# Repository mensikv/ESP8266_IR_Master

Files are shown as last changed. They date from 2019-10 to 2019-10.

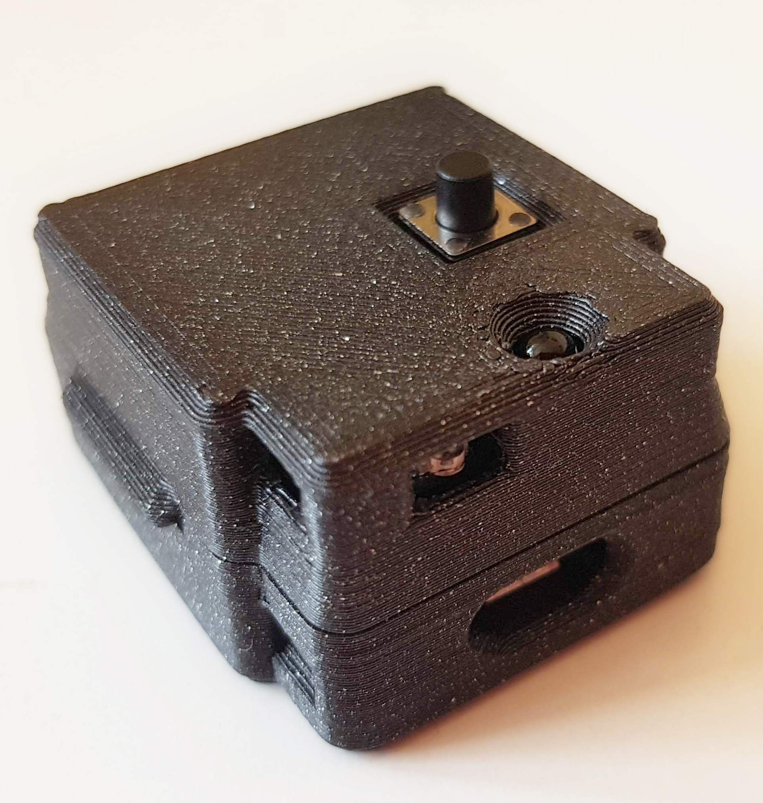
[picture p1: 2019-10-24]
photos/ESP8266_IR_Master_1.jpg

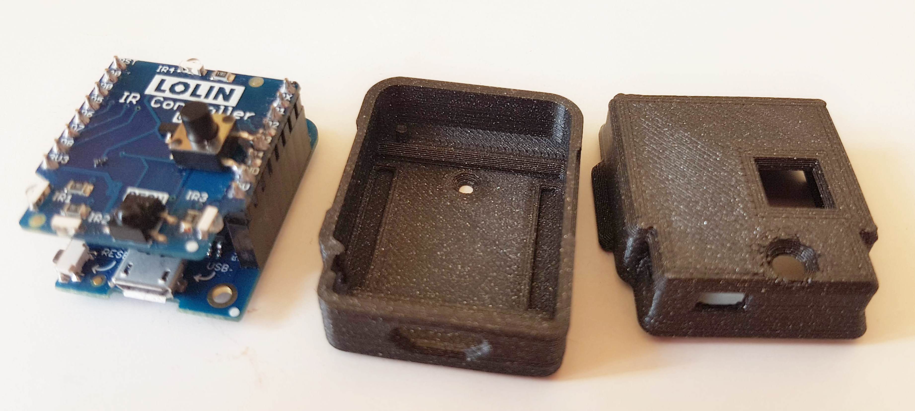
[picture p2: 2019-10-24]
photos/ESP8266_IR_Master_4.jpg

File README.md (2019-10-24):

# ESP8266 IR Master
The project is for ESP8266 boards and utilizes IR LEDs and IR receiver. Thanks to the IR receiver, you can scan various IR codes (from tv remotes, air-conditionings, lights...), save them to EEPROM on the ESP8266 and later send them through the IR LEDs.
Webserver runs on ESP8266 that provides interface for scanning and sending of IR codes. REST and MQTT API can also be enabled.
Project can be used in home automation systems for devices, that are controlled with IR remotes.
**WIFI networks is required**.

This project was created for workshop on [Mini Maker Fair Brno 2019](https://brno.makerfaire.com/).

## Prerequisites
### Hardware
It is possible to use any ESP8266 board and some IR LEDs and IR receiver, but I would recommend following combination:
* [Wemos (Lolin) D1 Mini](https://lolin.aliexpress.com/store/group/D1-D1-mini-Boards/1331105_505460007.html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) (non-affiliated link)
* [Wemos (Lolin) IR shield](https://www.aliexpress.com/item/32891173618.html?spm=2114.12010612.8148356.1.32522730sTPRit) (non-affiliated link)

### Software
Project was tested with following versions:
* Arduino IDE 1.8.10
* ESP8266 core 2.5.2
* [ESP8266 Sketch Data Upload](https://github.com/esp8266/arduino-esp8266fs-plugin)

Libraries:
* [ArduinoJSON 6.12.0](https://github.com/bblanchon/ArduinoJson)
* [ESP_EEPROM 2.0.0](https://github.com/jwrw/ESP_EEPROM)
* [IRRemoteESP8266 2.6.6](https://github.com/crankyoldgit/IRremoteESP8266)
* [WifiManages 0.15.0-beta](https://github.com/tzapu/WiFiManager)
* [arduinoWebSockets 2.1.1](https://github.com/Links2004/arduinoWebSockets)
* [PubSubClient 2.7](https://github.com/knolleary/pubsubclient)
* [PinButton](https://github.com/poelstra/arduino-multi-button)

## Sending IR codes with a button
You can use a button to send selected IR codes, single click and double click is supported.
If you use Wemos D1 Mini with [IR shield](https://wiki.wemos.cc/products:d1_mini_shields:ir_controller_shield), use these steps:
1. Solder a button on the IR shield between pins D3 and GND.
1. Since D3 is by default used for IR LEDs, you must cut a trace on the back of the IR shield and join two solder pads - I have used pin D2 for IR LEDs.

## Setup
1. Download content of this repository to your Arduino folder (probably `~\Documents\Arduino\ESP8266_IR_Master`, folder should contain one `*.ino` file and `data` folder) and open `ESP8266_IR_Master.ino`.
1. Set pin for sending IR signals `const uint16_t kIrLedPin = D2;`
1. Set pin for receiving IR signals `const uint16_t kRecvPin = D4;`
1. You can set a hostname by changing `#define ESP_HOSTNAME "IRMASTER001"`
1. If you want to use button, set the pin, where button is connected: `#define BUTTON_PIN D3`
1. If you want to enable REST API (sending IR codes with GET requests), uncomment `//#define USE_REST_API`
1. If you want to enable MQTT API (sending IR codes with MQTT messages), uncomment `//#define USE_MQTT`
   1. In section `#ifdef USE_MQTT` set connection to your MQTT broker and topics, you want to use.
   1. You should increase `MQTT_MAX_PACKET_SIZE` in PubSubClient.h. For 5 IR codes is 512 sufficient - `#define MQTT_MAX_PACKET_SIZE 512`
1. If you want to assign static IP address to the board in your WIFI network, uncomment and set following line `//wifiManager.setSTAStaticIPConfig(IPAddress(192,168,0,99), IPAddress(192,168,0,1), IPAddress(255,255,255,0));`
1. Choose the right board and select Flash size with at least 128kB SPIFFS, on Wemos D1 Mini I have used 4M (1M SPIFFS)
1. Upload the code.
1. Run ESP8266 Sketch Data Upload to upload content of `/data` folder to SPIFFS on ESP8266. Great article is [Chapter 11 - SPIFFS](https://tttapa.github.io/ESP8266/Chap11%20-%20SPIFFS.html). ESP8266 Sketch Data Upload plug-in to load data on SPIFFS can be downloaded from [here](https://github.com/esp8266/arduino-esp8266fs-plugin). `/data` folder contains html code, CSS styles and JavaScript code for the webserver.
   1. Before stating upload to SPIFFS make sure, that Serial monitor window is not opened, otherwise the upload will fail.
1. Now the ESP8266 will start in AP mode (onboard LED blinks) and creates WIFI network with the name you set as hostname. Connect to this network and you should be redirected to URL 192.168.0.1 (if not, enter this address in your browser). On this page set up WIFI connection to your network. ESP8266 will try to connect to it, if it succeeds the onboard LED stops blinking.
1. Either check your router or Serial monitor to find out, what IP address the ESP8266 got. Enter this address in your browser.
1. You enter a web interface with 3 tabs, 1st tab is used to send IR codes (it is empty, until you scan and save some IR codes). 2nd tab is used to scan new IR codes (click Scan button and then you have 5seconds to fire IR signal on the IR receiver. If successful, you can name it and save), delete some IR codes and also assign some codes to click or double click of the button. 3rd tab is short help.

## REST API
If you enable REST API, then the ESP8266 will provide two new URLs:
* http://IPADDRESS/api?all
  * returns JSON with saved IR codes and their IDs
* http://IPADDRESS/api?fire=IR_ID
  * sends IR signal with id IR_ID and returns JSON with success or error

## MQTT API
If you enable MQTT API, then the ESP8266 will wait for commands in topic:
* MQTT_TOPIC/cmd with payloads
  * "all" - returns JSON with saved IR codes in topic MQTT_TOPIC/all
  * "fire IR_ID" - sends IR signal with id IR_ID and returns JSON with success or error in topic MQTT_TOPIC/fire

## STL for case
In folder `case` you will find `*.stl` files for your 3D printer, so you can print nice case for Wemos D1 Mini with IR shield.
More information about the case and photos can be found on [Thingiverse](https://www.thingiverse.com/thing:3930823).

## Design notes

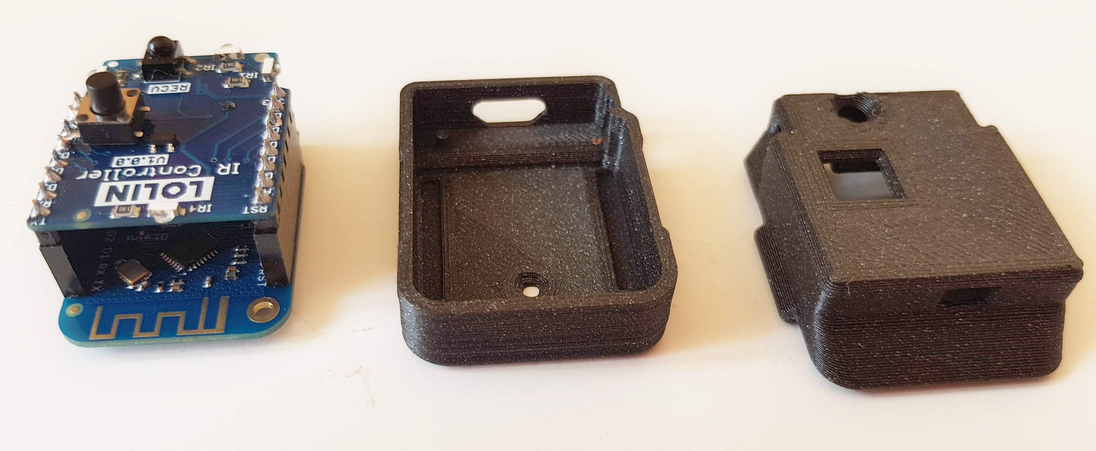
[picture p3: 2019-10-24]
photos/ESP8266_IR_Master_5.jpg

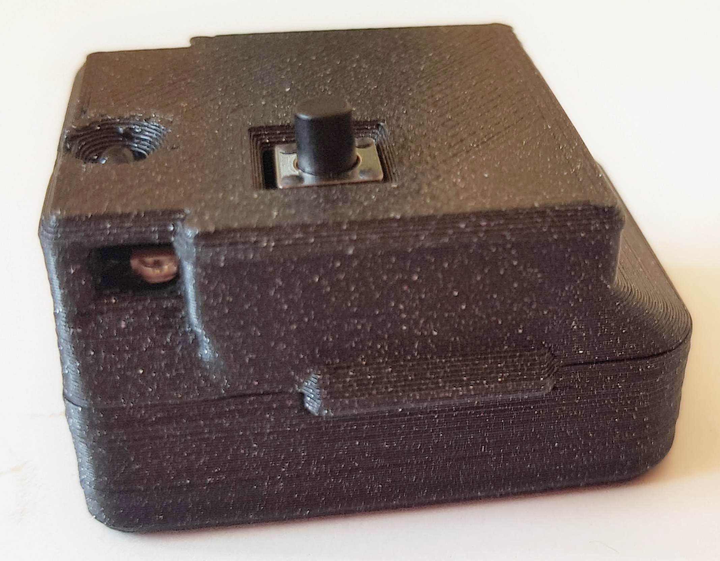
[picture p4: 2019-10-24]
photos/ESP8266_IR_Master_2.jpg

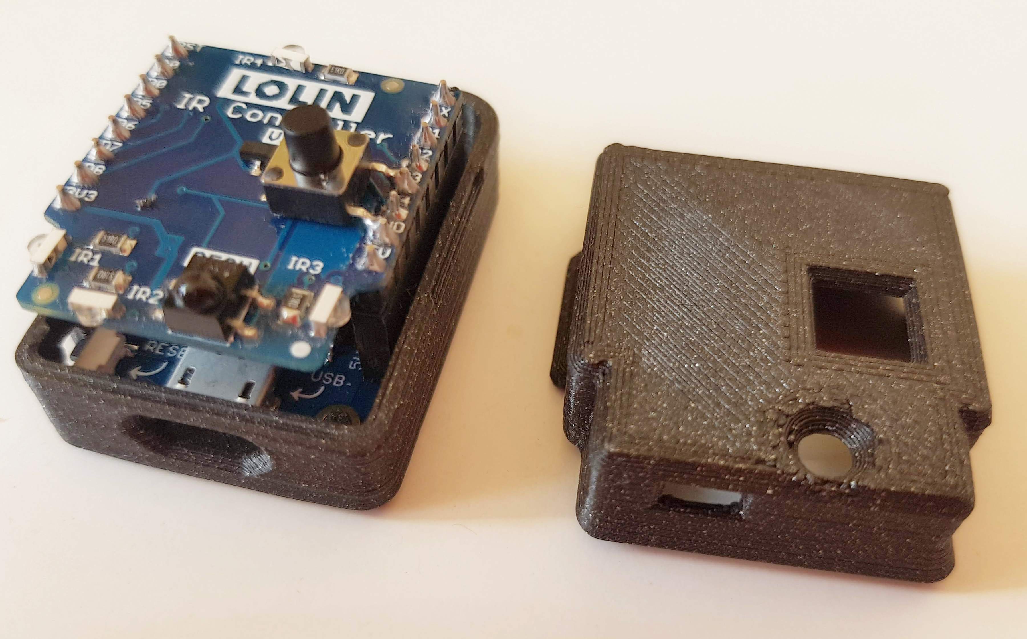
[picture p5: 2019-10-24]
photos/ESP8266_IR_Master_3.jpg

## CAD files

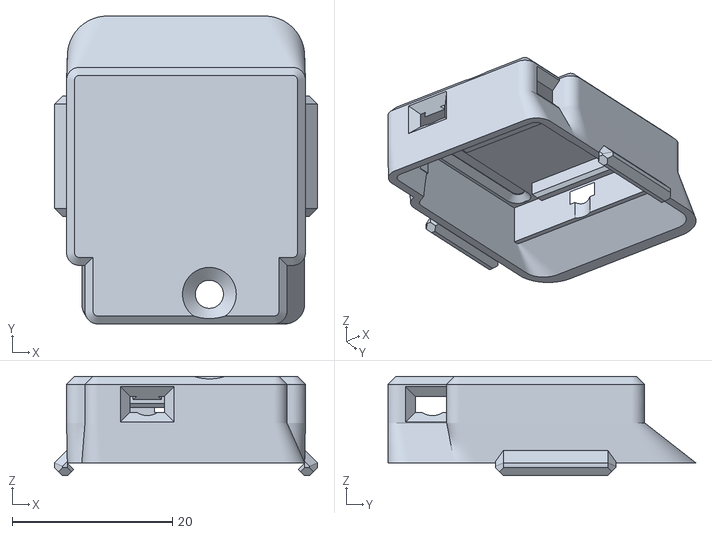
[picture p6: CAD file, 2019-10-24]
case/ESP8266_IR_Master-case-top.stl
32.8 x 38.4 x 12.4

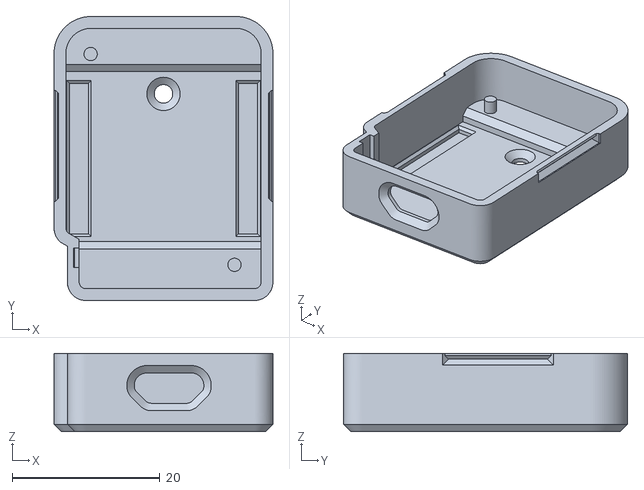
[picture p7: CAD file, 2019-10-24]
case/ESP8266_IR_Master-case-bottom.stl
29.6 x 38.4 x 10.6

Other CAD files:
case/ESP8266_IR_Master-case-top-button.stl

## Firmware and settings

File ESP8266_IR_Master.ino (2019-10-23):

/*
  ####
  ## ESP8266 IR Master
  ####
  Board: Lolin(Wemos) D1 R2 & mini
  Flash size: 4M (1M SPIFFS)
  When you want to erase EEPROM: Erase Flash: All Flash Contents

  upload code a then upload files

  use ESP8266 Sketch Data Upload to upload files to ESP8266 SPIFFS: // https://github.com/esp8266/arduino-esp8266fs-plugin
  data\index.html.gz
  data\bootstrap.min.js.gz
  data\jquery-3.4.1.min.js.gz
  data\bootstrap.min.css.gz
  data\favicon.ico

  Tested with versions:
  Arduino IDE 1.8.10

  ESP8266 core 2.5.2

  Libraries:
  ArduinoJSON 6.12.0
  ESP_EEPROM 2.0.0
  IRRemoteESP8266 2.6.6
  WifiManages 0.15.0-beta
  arduinoWebSockets 2.1.1
  PubSubClient 2.7
    you should increase MQTT_MAX_PACKET_SIZE in PubSubClient.h for 5 irCodes is 512 sufficient
      #define MQTT_MAX_PACKET_SIZE 512
*/

#include <Arduino.h>
#include <FS.h>
#include <Ticker.h>
#include <ESP8266WiFi.h>          //ESP8266 Core WiFi Library
#include <DNSServer.h>            //Local DNS Server used for redirecting all requests to the configuration portal - needed for WifiManager
#include <ESP8266WebServer.h>     //Local WebServer used to serve the configuration portal

#include <WiFiManager.h>          // https://github.com/tzapu/WiFiManager WiFi Configuration Magic
#include <ESP_EEPROM.h>           // https://github.com/jwrw/ESP_EEPROM
#include <PinButton.h>            // https://github.com/poelstra/arduino-multi-button
#include <ArduinoJson.h>          // https://github.com/bblanchon/ArduinoJson
#include <WebSocketsServer.h>     // https://github.com/Links2004/arduinoWebSockets
#include <IRremoteESP8266.h>      // https://github.com/crankyoldgit/IRremoteESP8266
#include <IRrecv.h>
#include <IRsend.h>
#include <IRutils.h>

/*
  ## WIFI Manager function
  When your ESP starts up, it sets it up in Station mode and tries to connect to a previously saved Access Point
  if this is unsuccessful (or no previous network saved) it moves the ESP into Access Point mode and spins up a DNS and WebServer (ip 192.168.0.1)
  using any wifi enabled device with a browser (computer, phone, tablet) connect to the newly created Access Point
  because of the Captive Portal and the DNS server you will either get a 'Join to network' type of popup or get any domain you try to access redirected to the configuration portal
  choose one of the access points scanned, enter password, click save
  ESP will try to connect. If successful, it relinquishes control back to your app. If not, reconnect to AP and reconfigure.
*/

#define ESP_HOSTNAME "IRMASTER001"

#define IR_CODE_COUNT 5                       // Number of IR codes that could be learned
#define IR_CODE_NAME_MAX_LENGTH 20            // Maximum length of IR code name (excluding ending 0)
#define IR_DEFAULT_REPEAT_COUNT 2             // how many times is an IR code fired
#define IR_DEFAULT_REPEAT_INTERVAL_MS 5       // how many milliseconds between IR code firing
#define MAX_REC_IR_WAITING_TIME_MS 5000       // How long to wait for IR code when learning new one

// APIs - if one is not needed, it should be commented
//#define USE_REST_API                          // /api?all - JSON with all ir codes; /api?fire=irCodeIndex - sends ir Code with irCodeIndex index
//#define USE_MQTT                              // all/fire

#define BUTTON_PIN D3                         // Pin where the button is connected
#define KBAUDRATE 115200                      // The Serial connection baud rate.

#define BUTTON_NO_CLICK 0
#define BUTTON_SINGLE_CLICK 1
#define BUTTON_DOUBLE_CLICK 2

#ifdef USE_MQTT
#include <PubSubClient.h>                     // https://github.com/knolleary/pubsubclient
#define MQTT_SERVER "192.168.1.201"
#define MQTT_USERNAME "irmaster"
#define MQTT_PASSWORD "password"
#define MQTT_TOPIC           ESP_HOSTNAME
#define MQTT_CMD_TOPIC       MQTT_TOPIC "/cmd"                  // payload "all", "fire x", where x is irCodeIndex
#define MQTT_ALL_TOPIC       MQTT_TOPIC "/all"                  // response JSON with all ir codes
#define MQTT_FIRE_TOPIC      MQTT_TOPIC "/fire"                 // response JSON with information about success or error
#define MQTT_LAST_WILL_TOPIC MQTT_TOPIC "/live"
#define MQTT_LAST_WILL "OFF"
#endif

// ==================== IRremoteESP8266 TUNEABLE PARAMETERS ====================
// The GPIO an IR detector/demodulator is connected to.
const uint16_t kRecvPin = D4;

// GPIO to use to control the IR LED circuit.
const uint16_t kIrLedPin = D2;

// As this program is a special purpose capture/resender, let's use a larger than expected buffer so we can handle very large IR messages.
const uint16_t kCaptureBufferSize = 1024;  // 1024 == ~511 bits

// kTimeout is the Nr. of milli-Seconds of no-more-data before we consider a message ended.
const uint8_t kTimeout = 50;  // Milli-Seconds

// kFrequency is the modulation frequency all UNKNOWN messages will be sent at.
const uint16_t kFrequency = 38000;  // in Hz. e.g. 38kHz.


// ==================== Types definition ====================
// structure to hold information about an IR code
typedef struct {
  char irCodeName[IR_CODE_NAME_MAX_LENGTH + 1];
  decode_type_t protocol;                   // NEC, SONY, RC5, UNKNOWN
  uint16_t irCodeLength;                    // number of bytes in irCodeState or number of bits in irCodeValue or number of raw data in irCodeRaw
  union {
    uint64_t irCodeValue;                   // Decoded value - a simple message protocol. ie. <= 64 bits
    uint8_t  irCodeState[kStateSizeMax];    // Multi-byte results for AC protocol with states
    uint16_t irCodeRaw[kRawBuf];
  };
} irCodeType;

// Settings
typedef struct {
  uint8_t irCodeCount;                  // 1 byte, Number of learned IR codes
  uint8_t singleClickIRCodeId;          // 1 byte, Index for IR code associated with button single click
  uint8_t doubleClickIRCodeId;          // 1 byte, Index for IR code associated with button double click
} irMasterSettingType;

typedef struct {                        // structure, that is written into the EEPROM memory
  uint32_t crc32;                       // 4 bytes
  irMasterSettingType irMasterSetting;
  irCodeType irCodes[IR_CODE_COUNT];
} irMasterEEPROMType;

// ==================== Global variables ====================
irMasterEEPROMType   irMasterEEPROM;          // contains all IR codes, CRC32 and other informations
irCodeType           *irCodes;                // IR codes the application operates with
irMasterSettingType  *irMasterSetting;        // Will containt info about button, number of learned IR codes and CRC32 of EEPROM
irCodeType irCode;                            // Will contain new IR code when learning

// Strings for storing JSON and IR codes
String strVar;   // reserve for 512 characters
String output;   // reserve for 768 characters

// The IR transmitter.
IRsend irsend(kIrLedPin);

// Web serever will run on port 80
ESP8266WebServer server(80);

// Websocket server will run on port 81
WebSocketsServer websocket_server = WebSocketsServer(81);

// Ticker is used to periodically call an function - we use it to blink the LED during WIFI setup
Ticker ticker;

// Create a new button object, listening on pin BUTTON_PIN = D3.
PinButton myButton(BUTTON_PIN);

#ifdef USE_MQTT
WiFiClient espWifiClient;
PubSubClient mqtt_client(espWifiClient);
#endif


// ==================== WIFI AP configuration ====================
// Function will turn on/off LED on Wemos board
void tick() {
  digitalWrite(LED_BUILTIN, !digitalRead(LED_BUILTIN));
}

// When Wifi Manager could not connecct to WIFI, it will start up its own AP with configuration portal. During configuration we will blink the LED
void startWMConfig(WiFiManager *wmp) {
  // every 200 ms call function tick
  ticker.attach(0.2, tick);
}

// Once WIFI configuration end, we stop blinking
void endWMConfig() {
  ticker.detach();
  digitalWrite(LED_BUILTIN, HIGH);
}


// ==================== ArduinoJSON examples ====================
/*
  //Adding array of objects - {"elem":[{"elem1":1},{"elem2":2}]}
  JsonArray elem = responseJSON.createNestedArray("elem");
  JsonObject elem1 = elem.createNestedObject();
  elem1["elem1"] = 1;
  JsonObject elem2 = elem.createNestedObject();
  elem2["elem2"] = 2;

  // Adding array {"elem":[1, 2]}
  JsonArray elem = responseJSON.createNestedArray("elem");
  elem.add(1);
  elem.add(2);

  // Adding Object {"elem":{"elem1":1,"elem2":2}}
  JsonObject elem = responseJSON.createNestedObject("elem");
  elem["elem1"] = 1;
  elem["elem2"] = 2;
*/

// ==================== JSON responses ====================
void allResponse (bool longFormat = false) {
  // create object for creating JSON
  //biggest JSON object:{"rsT":"all", "rsS":"OK", "rsE":"","rsV":[{"id":0,"name":"TV on", "ir":"123456", "btn":0},{"id":1,"name":"TV off", "ir":"987654", "btn":1},{"id":1,"name":"TV off", "ir":"987654", "btn":2},{"id":1,"name":"TV off", "ir":"987654", "btn":0},{"id":1,"name":"TV off", "ir":"987654", "btn":0}]}
  const int capacityResponseJSON = JSON_ARRAY_SIZE(5) + 6 * JSON_OBJECT_SIZE(4) + 256;
  StaticJsonDocument<capacityResponseJSON> responseJSON;
  //StaticJsonDocument<1024> responseJSON;
  responseJSON["rsT"] = "all";
  responseJSON["rsS"] = "OK";
  responseJSON["rsE"] = "";
  output = "";
  yield();
  //{rsT:"all", rsS:"OK", rsE:"",rsV:[{id:0,name:"TV on", ir:"123456", "btn":0},{id:1,name:"TV off", ir:"987654", "btn":1}]};
  JsonArray rsV = responseJSON.createNestedArray("rsV");
  for (uint8_t i = 0; i < IR_CODE_COUNT; i++) {
    if (irCodes[i].irCodeLength > 0) {
      JsonObject irCodeElem = rsV.createNestedObject();
      irCodeElem["id"] = i;
      irCodeElem["name"] = irCodes[i].irCodeName;
      if (longFormat) {
        irCodeElem["ir"] = getIRCode(&irCodes[i], false);
        if (i == irMasterSetting->singleClickIRCodeId) irCodeElem["btn"] = BUTTON_SINGLE_CLICK;
        else if (i == irMasterSetting->doubleClickIRCodeId) irCodeElem["btn"] = BUTTON_DOUBLE_CLICK;
        else irCodeElem["btn"] = BUTTON_NO_CLICK;
      }
    }
  }
  serializeJson(responseJSON, output);
  yield();
}

void scanResponse (uint8_t scanResult) {
  // create object for creating JSON
  const int capacityResponseJSON = JSON_OBJECT_SIZE(4) + 100;
  StaticJsonDocument<capacityResponseJSON> responseJSON;
  responseJSON["rsT"] = "scan";
  responseJSON["rsS"] = "OK";
  responseJSON["rsE"] = "";
  output = "";
  yield();
  //{"rsT":"scan", "rsS":"OK", "rsE":"","rsV":"123456"}
  if (scanResult == 1) {
    responseJSON["rsV"] = getIRCode(&irCode, false);
  } else {
    responseJSON["rsS"] = "ERROR";
    responseJSON["rsE"] = (scanResult == 0) ? "IR code scan timeout" : "IR code overflow";
  }
  serializeJson(responseJSON, output);
  yield();
}

void fireResponse (uint8_t fireResult, const uint8_t irCodeIndex) {
  // create object for creating JSON
  const int capacityResponseJSON = JSON_OBJECT_SIZE(4) + 60;
  StaticJsonDocument<capacityResponseJSON> responseJSON;
  responseJSON["rsT"] = "fire";
  responseJSON["rsS"] = "OK";
  responseJSON["rsE"] = "";
  responseJSON["rsV"] = irCodeIndex;
  output = "";
  yield();
  //{"rsT":"fire", "rsS":"OK", "rsE":"","rsV":9}
  if (fireResult != 1) {
    responseJSON["rsS"] = "ERROR";
    responseJSON["rsE"] = (fireResult == 0) ? "Error during sending of IR code" : "Non-existing index";
  }
  serializeJson(responseJSON, output);
  yield();
}

void deleteResponse (uint8_t deleteResult, const uint8_t irCodeIndex) {
  // create object for creating JSON
  const int capacityResponseJSON = JSON_OBJECT_SIZE(4) + 60;
  StaticJsonDocument<capacityResponseJSON> responseJSON;
  responseJSON["rsT"] = "delete";
  responseJSON["rsS"] = "OK";
  responseJSON["rsE"] = "";
  responseJSON["rsV"] = irCodeIndex;
  output = "";
  yield();
  //{"rsT":"delete", "rsS":"OK", "rsE":"","rsV":9}
  if (deleteResult != 1) {
    responseJSON["rsS"] = "ERROR";
    responseJSON["rsE"] = (deleteResult == 0) ? "Error during deleting operation" : "Non-existing index";
  }
  serializeJson(responseJSON, output);
  yield();
}

void learnResponse (uint8_t learnResult, const uint8_t irCodeIndex) {
  // create object for creating JSON
  const int capacityResponseJSON = 2 * JSON_OBJECT_SIZE(4) + 60;
  StaticJsonDocument<capacityResponseJSON> responseJSON;
  responseJSON["rsT"] = "learn";
  responseJSON["rsS"] = "OK";
  responseJSON["rsE"] = "";
  output = "";
  yield();
  //{"rsT":"learn", "rsS":"OK", "rsE":"","rsV":{"id":0,"name":"TV on", "ir":"123456", "btn":0}}
  if (learnResult != 1) {
    responseJSON["rsS"] = "ERROR";
    if (learnResult == 0) responseJSON["rsE"] = "Could not save the new IR code to EEPROM.";
    else if (learnResult == 2) responseJSON["rsE"] = "No more IR codes can be learned. Delete some first.";
    else responseJSON["rsE"] = "There is no IR to learn. First use scan.";
  } else {
    JsonObject rsV = responseJSON.createNestedObject("rsV");
    rsV["id"] = irCodeIndex;
    rsV["name"] = irCodes[irCodeIndex].irCodeName;
    rsV["ir"] = getIRCode(&irCodes[irCodeIndex], false);
    rsV["btn"] = BUTTON_NO_CLICK;
  }
  serializeJson(responseJSON, output);
  yield();
}

void clickResponse (uint8_t clickResult, const uint8_t irCodeIndex) {
  // create object for creating JSON
  const int capacityResponseJSON = JSON_OBJECT_SIZE(2) + JSON_OBJECT_SIZE(4) + 60;
  StaticJsonDocument<capacityResponseJSON> responseJSON;
  responseJSON["rsT"] = "click";
  responseJSON["rsS"] = "OK";
  responseJSON["rsE"] = "";
  output = "";
  yield();
  //{"rsT":"click", "rsS":"OK", "rsE":"","rsV":{"id":5,"btn":1}}
  if (clickResult != 1) {
    responseJSON["rsS"] = "ERROR";
    if (clickResult == 0) responseJSON["rsE"] = "Could not save to EEPROM.";
    else responseJSON["rsE"] = "Non-existing index.";
  } else {
    JsonObject rsV = responseJSON.createNestedObject("rsV");
    rsV["id"] = irCodeIndex;
    if (irCodeIndex == irMasterSetting->singleClickIRCodeId) rsV["btn"] = BUTTON_SINGLE_CLICK;
    else if (irCodeIndex == irMasterSetting->doubleClickIRCodeId) rsV["btn"] = BUTTON_DOUBLE_CLICK;
    else rsV["btn"] = BUTTON_NO_CLICK;
  }
  serializeJson(responseJSON, output);
  yield();
}

// ==================== Websocket received event processing ====================
// This function is executed when we receive event through Websocket interface
void websocketProcess(uint8_t num, WStype_t type, uint8_t* data, size_t length) {
  digitalWrite(LED_BUILTIN, LOW);    // blick when processing

  if (type == WStype_CONNECTED) {
    IPAddress ip = websocket_server.remoteIP(num);
    Serial.printf("[%u] Connected from %d.%d.%d.%d url: %s\n", num, ip[0], ip[1], ip[2], ip[3], data);
    //websocket_server.sendTXT(num, "Connected");
  }
  else if (type == WStype_DISCONNECTED) {
    Serial.printf("[%u] Disconnected!\n", num);
  }
  else if (type == WStype_TEXT) {  // when we receive message from a client
    Serial.printf("[%u] get Text: %s\n", num, data);

    // create object for processing
    //biggest JSON object:{"rqT":"click","rqV":{"id":5,"btn":1}}
    const int capacityRequestJSON = 2 * JSON_OBJECT_SIZE(2) + 30;
    StaticJsonDocument<capacityRequestJSON> requestJSON;

    // Request messages
    // {"rqT":"all","rqV":1}
    // {"rqT":"scan","rqV":1}
    // {"rqT":"fire","rqV":id}
    // {"rqT":"delete","rqV":id}
    // {"rqT":"learn","rqV":"name"}
    // {"rqT":"click","rqV":{"id":5,"btn":1}}

    // parse incoming JSON message
    DeserializationError err = deserializeJson(requestJSON, data);
    if (err) {
      Serial.print(F("deserializeJson() failed with code "));
      Serial.println(err.c_str());
      digitalWrite(LED_BUILTIN, HIGH);
      return;
    }
    yield();

    if (requestJSON["rqT"] == "all") { // return all IR codes
      // ###########################
      // ## all
      // ###########################
      Serial.println(F("Received *all* request"));
      //{rsT:"all", rsS:"OK", rsE:"",rsV:[{id:0,name:"TV on", ir:"123456", "btn":0},{id:1,name:"TV off", ir:"987654", "btn":1}]};
      allResponse(true);
      Serial.printf("*all* response: %s\n", output.c_str());
      websocket_server.sendTXT(num, output);

    } else if (requestJSON["rqT"] == "scan") { // start scannig for IR codes and return scanned IR code
      // ###########################
      // ## scan
      // ###########################
      Serial.println(F("Received *scan* request"));
      // {rsT:"scan", rsS:"OK", rsE:"",rsV:"123456"};
      uint8_t scanResult = receiveIRCode();
      scanResponse(scanResult);
      Serial.printf("*scan* response: %s\n", output.c_str());
      websocket_server.sendTXT(num, output);

    } else if (requestJSON["rqT"] == "fire") { // fire (send) ir code and return success or error
      // ###########################
      // ## fire
      // ###########################
      Serial.println(F("Received *fire* request"));
      const uint8_t irCodeIndex = requestJSON["rqV"];
      //{rsT:"fire", rsS:"OK", rsE:"",rsV:9};
      uint8_t fireResult = sendIRCode(irCodeIndex);
      fireResponse(fireResult, irCodeIndex);
      Serial.printf("*fire* response: %s\n", output.c_str());
      websocket_server.sendTXT(num, output);

    } else if (requestJSON["rqT"] == "delete") { // delete ir code and return success or error
      // ###########################
      // ## delete
      // ###########################
      Serial.println(F("Received *delete* request"));
      const uint8_t irCodeIndex = requestJSON["rqV"];
      //{rsT:"delete", rsS:"OK", rsE:"",rsV:9};
      uint8_t deleteResult = deleteIRCode(irCodeIndex);
      deleteResponse(deleteResult, irCodeIndex);
      Serial.printf("*delete* response: %s\n", output.c_str());
      websocket_server.broadcastTXT(output);

    } else if (requestJSON["rqT"] == "learn") { // save last scanned ir code and return it to the client
      // ###########################
      // ## learn
      // ###########################
      Serial.println(F("Received *learn* request"));
      const char* irCodeName = requestJSON["rqV"];
      uint8_t newIRCodeIndex;
      uint8_t learnResult = learnIRCode(irCodeName, &newIRCodeIndex);
      //{rsT:"learn", rsS:"OK", rsE:"",rsV:{id:0,name:"TV on", ir:"123456", "btn":0}}
      learnResponse(learnResult, newIRCodeIndex);
      Serial.printf("*learn* response: %s\n", output.c_str());
      websocket_server.broadcastTXT(output);

    } else if (requestJSON["rqT"] == "click") { // associate button click/double click with an ir code, return succes/error
      // ###########################
      // ## click
      // ###########################
      Serial.println(F("Received *click* request"));
      const uint8_t irCodeIndex = requestJSON["rqV"]["id"];
      const uint8_t clickType = requestJSON["rqV"]["btn"];
      uint8_t clickResult = setButtonClick(irCodeIndex, clickType);
      //{"rsT":"click", "rsS":"OK", "rsE":"","rsV":{"id":5,"btn":1}}
      clickResponse(clickResult, irCodeIndex);
      Serial.printf("*click* response: %s\n", output.c_str());
      websocket_server.sendTXT(num, output);

    } else {
      Serial.println(F("Received not recognised request"));
      websocket_server.sendTXT(num, "ERROR - Received not recognised request");
    }

  } else {
    switch (type) {
      case WStype_ERROR: Serial.println(F("WStype_ERROR")); break;
      case WStype_BIN: Serial.println(F("WStype_BIN")); break;
      case WStype_FRAGMENT_TEXT_START: Serial.println(F("WStype_FRAGMENT_TEXT_START")); break;
      case WStype_FRAGMENT_BIN_START: Serial.println(F("WStype_FRAGMENT_BIN_START")); break;
      case WStype_FRAGMENT: Serial.println(F("WStype_FRAGMENT")); break;
      case WStype_FRAGMENT_FIN: Serial.println(F("WStype_FRAGMENT_FIN")); break;
      case WStype_PING: Serial.println(F("WStype_PING")); break;
      case WStype_PONG: Serial.println(F("WStype_PONG")); break;
    }
  }
  digitalWrite(LED_BUILTIN, HIGH);
}


// ==================== IR codes processing ====================
// Associate button click/double click with and IR code
uint8_t setButtonClick(uint8_t irCodeIndex, uint8_t clickType) {
  Serial.println(F("Set button click action."));
  Serial.printf("For index %i and value %i\n", irCodeIndex, clickType);
  uint8_t result = 1;
  if (!checkIRCodeExists(irCodeIndex)) {
    Serial.printf("Non-existing IR code index %i\n\n", irCodeIndex);
    return 2;
  }
  if ((clickType != BUTTON_NO_CLICK) && (clickType != BUTTON_SINGLE_CLICK) && (clickType != BUTTON_DOUBLE_CLICK)) clickType = BUTTON_NO_CLICK;
  if (clickType == BUTTON_NO_CLICK) {  // delete action but do not save
    if (irCodeIndex == irMasterSetting->singleClickIRCodeId) irMasterSetting->singleClickIRCodeId = IR_CODE_COUNT + 1;
    else if (irCodeIndex == irMasterSetting->doubleClickIRCodeId) irMasterSetting->doubleClickIRCodeId = IR_CODE_COUNT + 1;
  } else {
    if (clickType == BUTTON_SINGLE_CLICK) irMasterSetting->singleClickIRCodeId = irCodeIndex;
    else irMasterSetting->doubleClickIRCodeId = irCodeIndex;

    if (irMasterSetting->singleClickIRCodeId == irMasterSetting->doubleClickIRCodeId) {
      if (clickType == BUTTON_SINGLE_CLICK) irMasterSetting->doubleClickIRCodeId = IR_CODE_COUNT + 1;
      else irMasterSetting->singleClickIRCodeId = IR_CODE_COUNT + 1;
    }
  }
  result = saveEEPROM();
  return result;
}
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
  void loop() {
    unsigned long t = millis();
    webSocket.loop();
    server.handleClient();

    if((t - last_10sec) > 10 * 1000) {
        counter++;
        bool ping = (counter % 2);
        int i = webSocket.connectedClients(ping);
        USE_SERIAL.printf("%d Connected websocket clients ping: %d\n", i, ping);
        last_10sec = millis();
    }
  }
*/
